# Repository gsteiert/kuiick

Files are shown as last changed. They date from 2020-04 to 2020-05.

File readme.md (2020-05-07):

# KUIICK Board

## K32L2B USB to IIC Kit

This board is a tiny USB to Qwiic development board in a bread-board friendly DIP form factor.  In addition to micro USB and Qwiic connectors, it also has two buttons, SPI flash and two rows of 100mil pitch header footprints for additional expansion.  The MCU is an NXP K32L2B Arm Cortex-M0+ with crystal-less USB and integrated VBUS to 3V regulator.  All of this is packed into a 15mm X 20mm board.

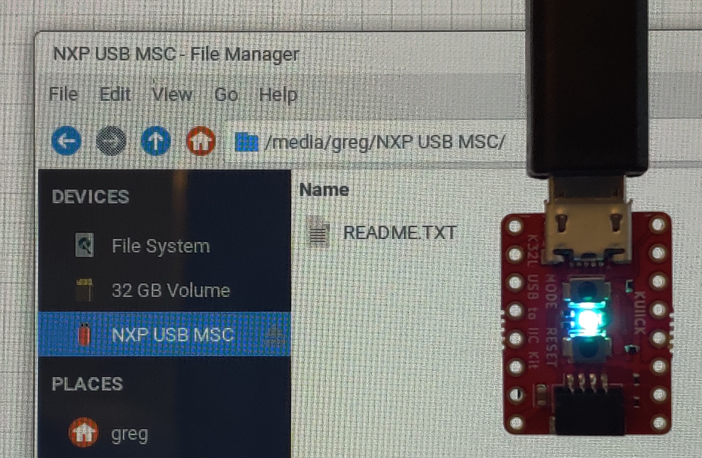
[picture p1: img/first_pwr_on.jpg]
first power on

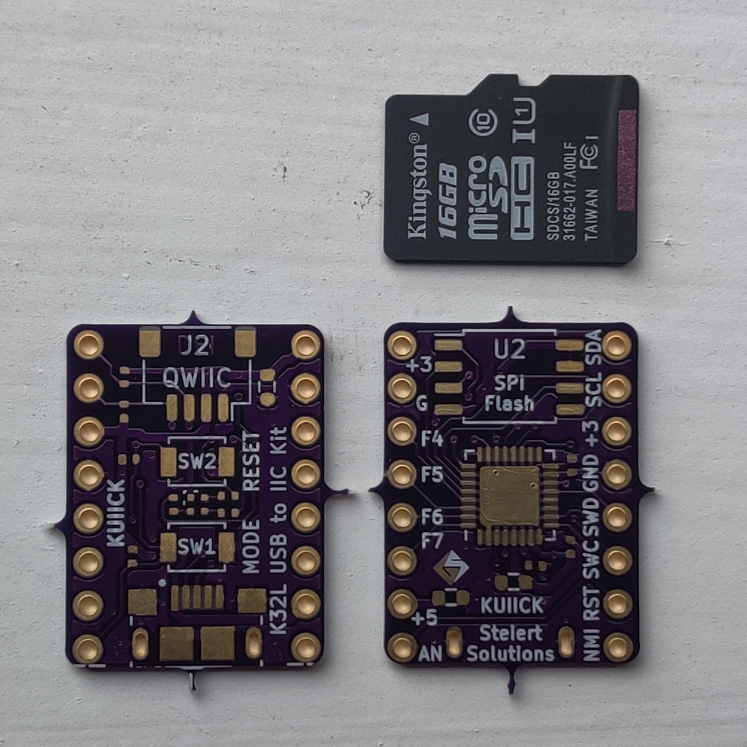
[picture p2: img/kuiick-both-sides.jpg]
pcb picture

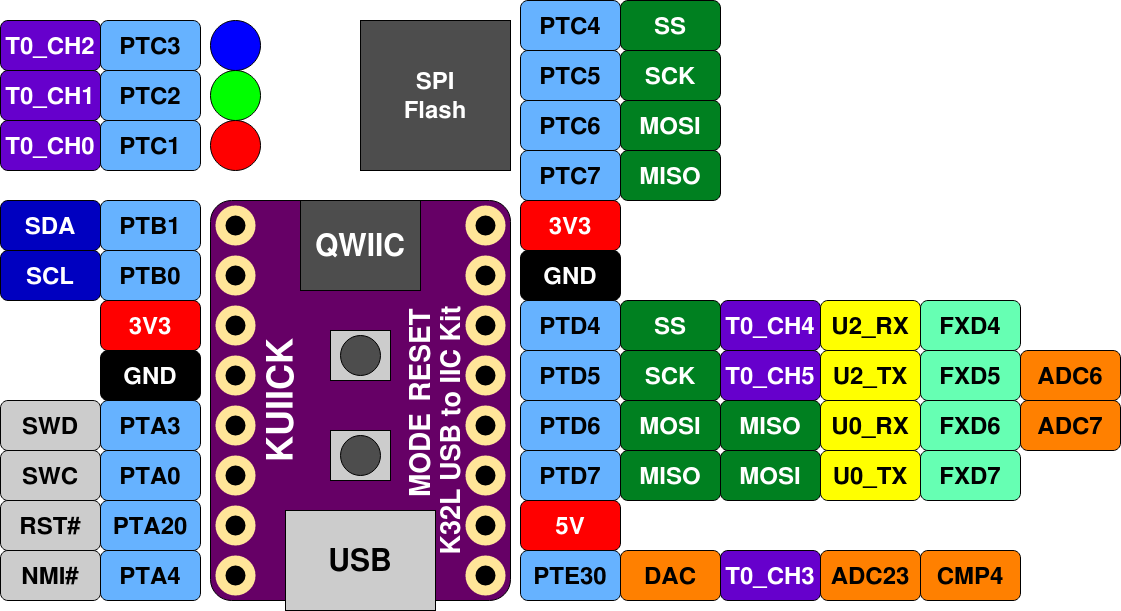
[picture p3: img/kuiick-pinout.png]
Pinout Drawing

[Schematic](kuiick_sch.pdf)

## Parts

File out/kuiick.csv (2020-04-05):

Id | Designator | Package | Quantity | Designation | Supplier and ref
1 | J2 | JST_SH_SM04B-SRSS-TB_1x04-1MP_P1.00mm_Horizontal | 1 | I2C_STANDARDQWIIC
2 | J4,J3 | PinHeader_1x08_P100mil_Vertical | 2 | Conn_01x08
3 | SW2,SW1 | SW_SPST_B3U-1000P_tight | 2 | SW_SPST
4 | R7,R6,R5,R4 | C0402 | 4 | 10K
5 | U2 | SOIC-8_5.23x5.23mm_P1.27mm | 1 | W25Q32JVSS
6 | C1,C8 | C0603 | 2 | 2.2UF
7 | J1 | FCI_10118193-0001LF | 1 | 10118193-0001LF
8 | C13,C12,C11 | C0402 | 3 | 0.1UF
9 | C9 | C0603 | 1 | 10UF
10 | R1 | C0402 | 1 | 2K
11 | R3,R2 | C0402 | 2 | 1K
12 | D1 | LED_RGB_1x1mm_CW | 1 | LED_ARBG
13 | U1 | QFN-32-1EP_5x5mm_P0.5mm_EP3.45x3.45mm | 1 | MK32L2B_QFN32

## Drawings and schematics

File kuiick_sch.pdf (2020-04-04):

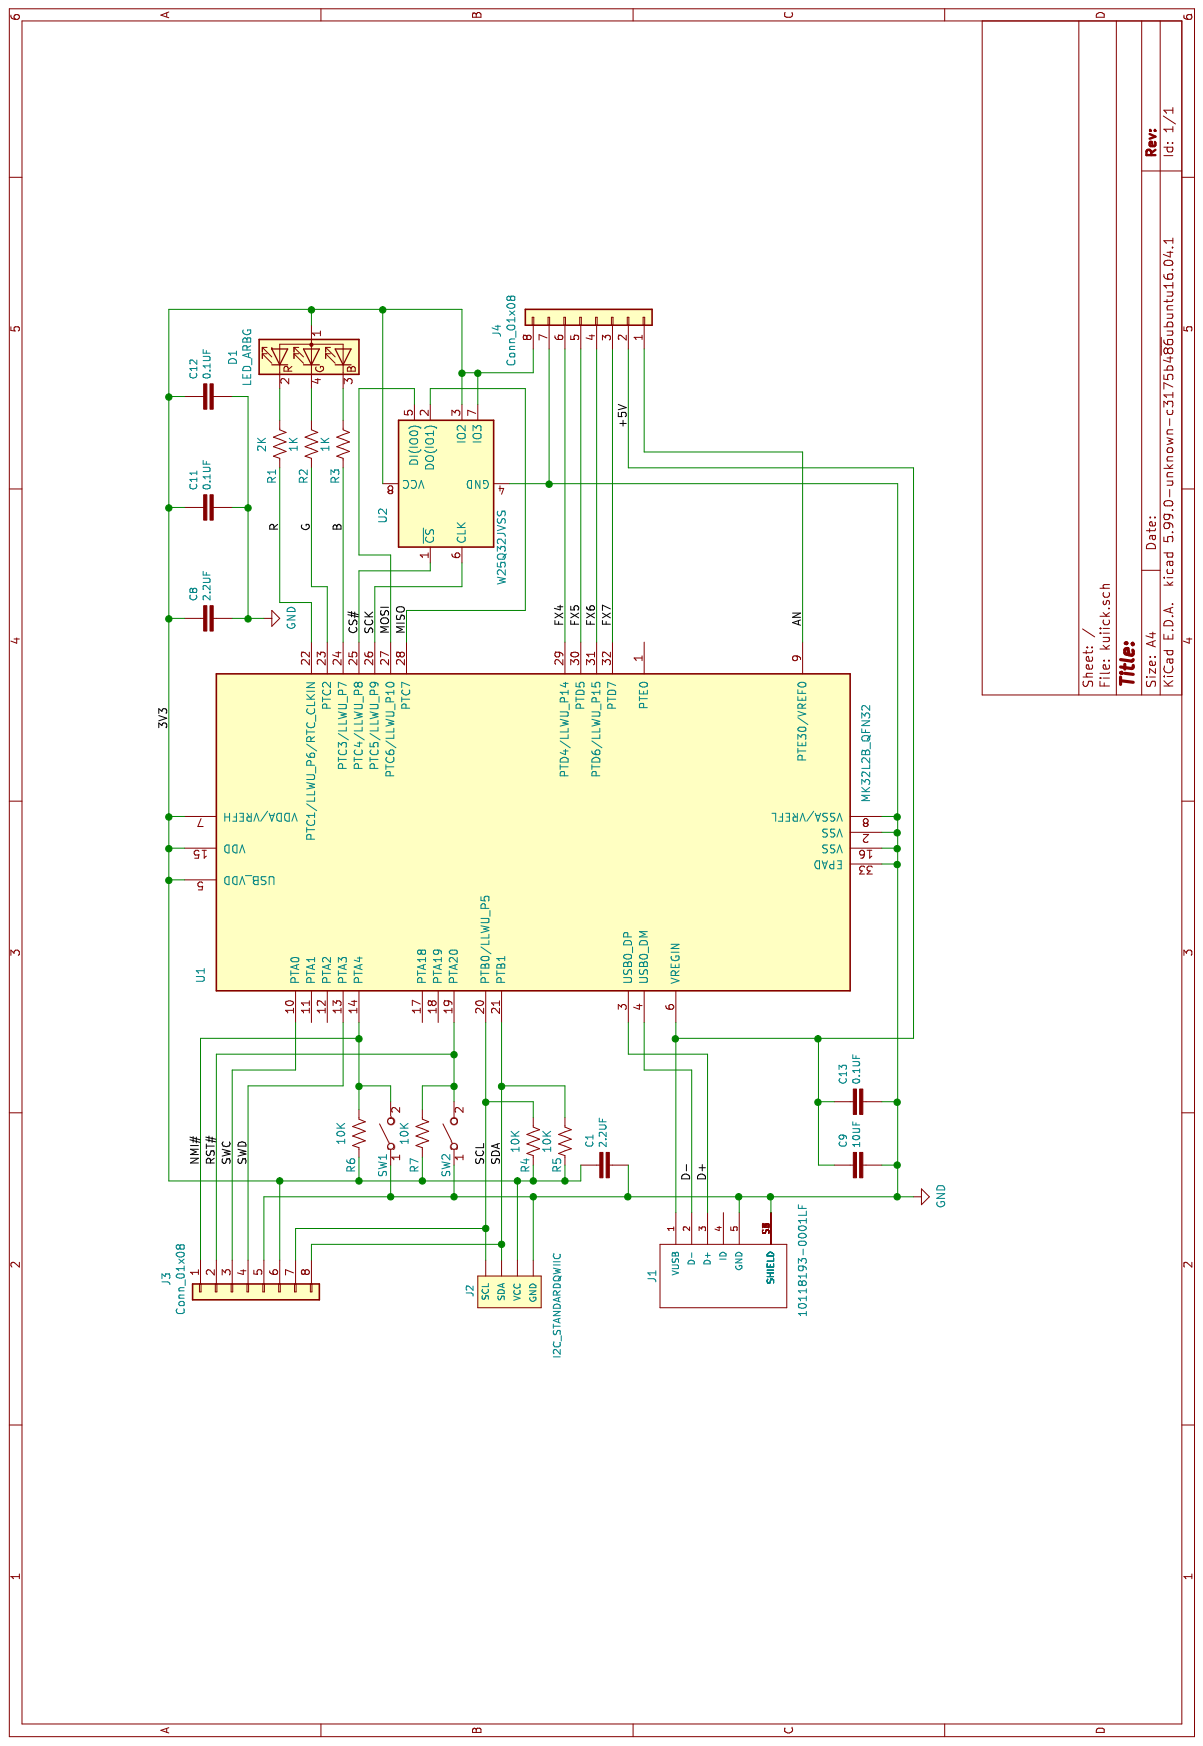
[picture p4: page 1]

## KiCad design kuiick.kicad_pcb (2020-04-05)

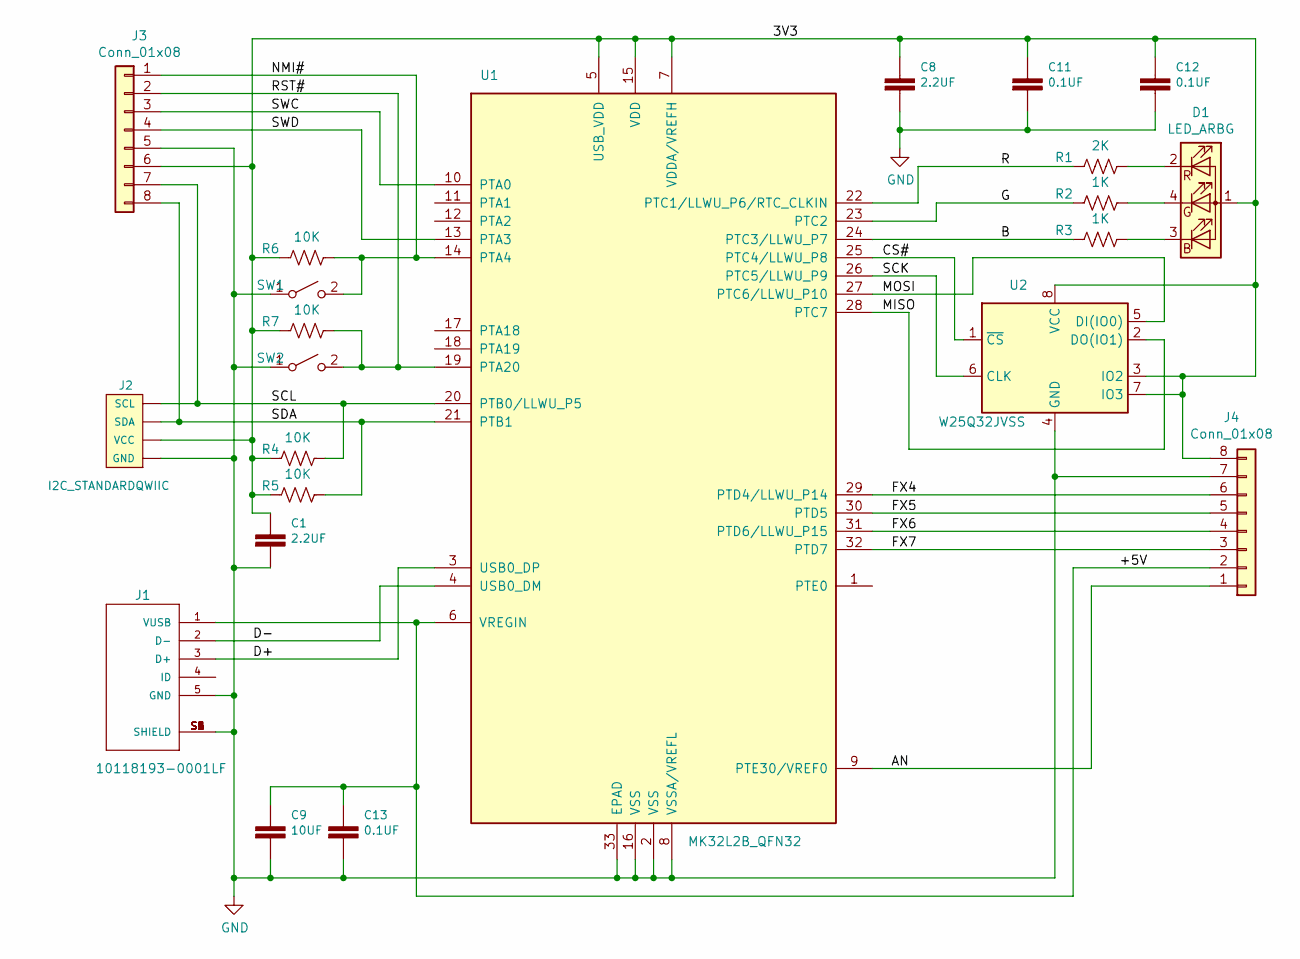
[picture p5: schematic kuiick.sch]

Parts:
C1, C8: 2.2UF; C0603
C9: 10UF; C0603
C11, C12, C13: 0.1UF; C0402
D1: LED_ARBG; LED_RGB_1x1mm_CW
J1: 10118193-0001LF; FCI_10118193-0001LF
J2: I2C_STANDARDQWIIC; 1X04_1MM_RA
J3, J4: Conn_01x08; PinHeader_1x08_P100mil_Vertical
R1: 2K; C0402
R2, R3: 1K; C0402
R4, R5, R6, R7: 10K; C0402
SW1, SW2: SW_SPST; SW_SPST_B3U-1000P_tight
U1: MK32L2B_QFN32; QFN-32-1EP_5x5mm_P0.5mm_EP3.45x3.45mm
U2: W25Q32JVSS; SOIC-8_5.23x5.23mm_P1.27mm

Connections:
/3V3: C1.1, C8.1, C11.1, C12.1, D1.1 (A), J2.2 (VCC), J3.6, J4.8, R4.2, R5.2, R6.2, R7.2, U1.5 (USB_VDD), U1.7 (VDDA/VREFH), U1.15 (VDD), U2.3 (IO2), U2.7 (IO3), U2.8 (VCC)
/+5V: C9.1, C13.1, J1.1 (VUSB), J4.2, U1.6 (VREGIN)
/AN: J4.1, U1.9 (PTE30/VREF0)
/B: R3.2, U1.24 (PTC3/LLWU_P7)
/CS#: U1.25 (PTC4/LLWU_P8), U2.1 (~CS)
/D+: J1.3 (D+), U1.3 (USB0_DP)
/D-: J1.2 (D-), U1.4 (USB0_DM)
/FX4: J4.6, U1.29 (PTD4/LLWU_P14)
/FX5: J4.5, U1.30 (PTD5)
/FX6: J4.4, U1.31 (PTD6/LLWU_P15)
/FX7: J4.3, U1.32 (PTD7)
/G: R2.2, U1.23 (PTC2)
/MISO: U1.28 (PTC7), U2.2 (DO(IO1))
/MOSI: U1.27 (PTC6/LLWU_P10), U2.5 (DI(IO0))
/NMI#: J3.1, R6.1, SW1.2 (B), U1.14 (PTA4)
/R: R1.2, U1.22 (PTC1/LLWU_P6/RTC_CLKIN)
/RST#: J3.2, R7.1, SW2.2 (B), U1.19 (PTA20)
/SCK: U1.26 (PTC5/LLWU_P9), U2.6 (CLK)
/SCL: J2.4 (SCL), J3.7, R4.1, U1.20 (PTB0/LLWU_P5)
/SDA: J2.3 (SDA), J3.8, R5.1, U1.21 (PTB1)
/SWC: J3.3, U1.10 (PTA0)
/SWD: J3.4, U1.13 (PTA3)
GND: C1.2, C8.2, C9.2, C11.2, C12.2, C13.2, J1.5 (GND), J1.None, J1.S1 (SHIELD), J1.S2 (SHIELD), J1.S3 (SHIELD), J1.S4 (SHIELD), J1.S5 (SHIELD), J1.S6 (SHIELD), J2.1 (GND), J3.5, J4.7, SW1.1 (A), SW2.1 (A), U1.2 (VSS), U1.8 (VSSA/VREFL), U1.16 (VSS), U1.33 (EPAD), U2.4 (GND)
unnamed: D1.2 (RK), R1.1
unnamed: D1.3 (BK), R3.1
unnamed: D1.4 (GK), R2.1

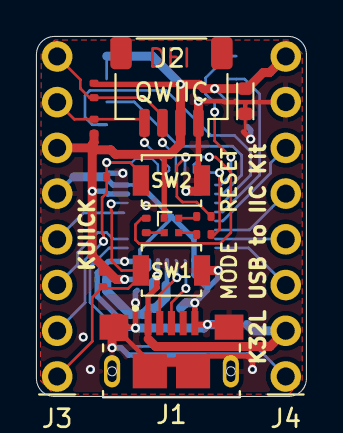
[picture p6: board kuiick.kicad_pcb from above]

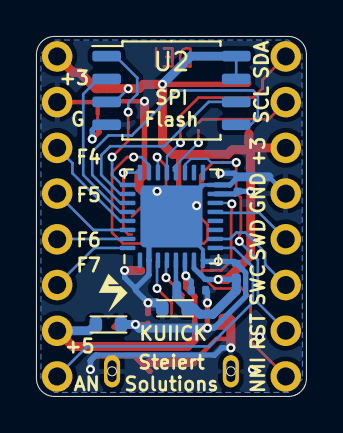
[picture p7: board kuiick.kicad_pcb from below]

Board: 2 copper layers, 15.0 x 20.0 mm, 22 parts (7 on the bottom side), 26 nets.

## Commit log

2020-03-21 initial commit, fully routed 14 pin dip
    [kuiick-B_Cu.gbr, kuiick-B_Mask.gbr, kuiick-B_Paste.gbr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]
2020-03-22 fully routed dip 16
    [kuiick.kicad_pcb, kuiick.sch]
2020-03-22 cleaned up silk, added logo
    [kuiick.kicad_pcb]
2020-03-22 clean up silk, swapped qwiic footprint
    [kuiick.kicad_pcb]
2020-03-22 clean up fills
    [kuiick.kicad_pcb]
2020-04-04 added schematic in pdf
2020-04-05 added pdf schematic and xyrs file
    [kuiick-B_Cu.gbr, kuiick-B_Mask.gbr, kuiick-B_Paste.gbr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]
2020-05-07 added first power on pic
